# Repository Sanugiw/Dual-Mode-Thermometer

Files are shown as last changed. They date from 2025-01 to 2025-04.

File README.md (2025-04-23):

# 🏥 Dual-Mode Analog Thermometer  

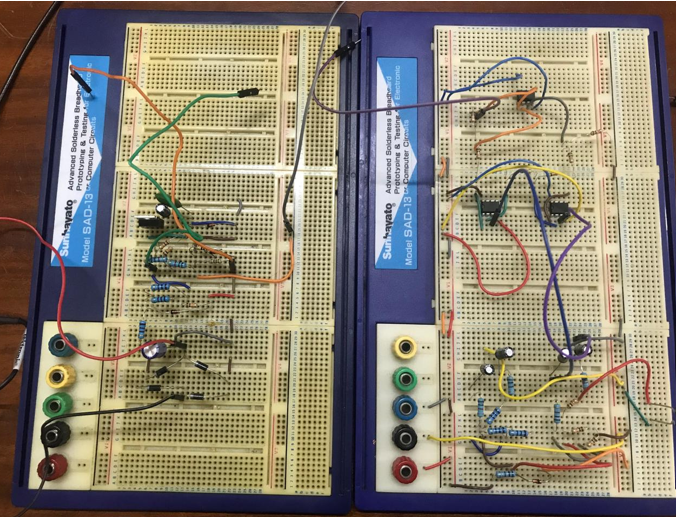
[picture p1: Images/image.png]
Project Banner
 <!-- Add an image of your device or schematic if available -->

## 📌 Overview  
The **Dual-Mode Analog Thermometer** is a precision temperature measurement device designed using **analog components** to ensure high accuracy and reliability. Unlike fully digital thermometers, this design utilizes **thermistors, Wheatstone bridges, and an instrumentation amplifier** for precise temperature readings.  

This project was developed as part of the **EN2091 Laboratory Practice and Projects** module in our 3rd semester, focusing on **hands-on circuit design, sensor integration, and analog signal processing**.  

## ⚡ Features  
✅ **Dual-Mode Functionality** – Toggle switch to switch between **body temperature** and **liquid temperature** modes.  
✅ **High Accuracy** – Uses **thermistors, Wheatstone bridges, and an instrumentation amplifier** for precise readings.  
✅ **OLED Display** – Temperature readings are displayed on an **OLED screen**, with an **Arduino** used solely for display purposes.  
✅ **Stable Power Supply** – Converts **AC to +10V, -10V, and 5V** for reliable operation.  
✅ **Future Expansion** – Plans to integrate a **MUX** for additional modes.  

## 🛠️ Development Tools  
- **Circuit Simulation**: 🖥️ LTspice  
- **Schematic & PCB Design**: 🖊️ Altium Designer  
- **Enclosure Modeling**: 📐 SolidWorks  

## 📷 Hardware Overview  
| Component | Function |
|---|---|
| **Thermistors** (NTC/PTC)  | Temperature sensing  |
| **Wheatstone Bridge**  | Signal conditioning |
| **Instrumentation Amplifier** | Precise signal amplification |
| **OLED Display** | Displays temperature readings |
| **Arduino** | Handles display functionality |
| **Power Supply** | Converts AC to +10V, -10V, and 5V |

## 🧩 Schematic & PCB Design

We designed both the **schematic** and **printed circuit boards (PCBs)** using **Altium Designer**. The project includes:

- 🧠 **Main Thermometer PCB** – Houses the signal conditioning circuit using Wheatstone bridges, thermistors, and an instrumentation amplifier.
- 🔋 **Dual Power Supply PCB** – Converts AC input into stable **+10V, -10V, and 5V** DC outputs. 

### 🖼️ Visuals:
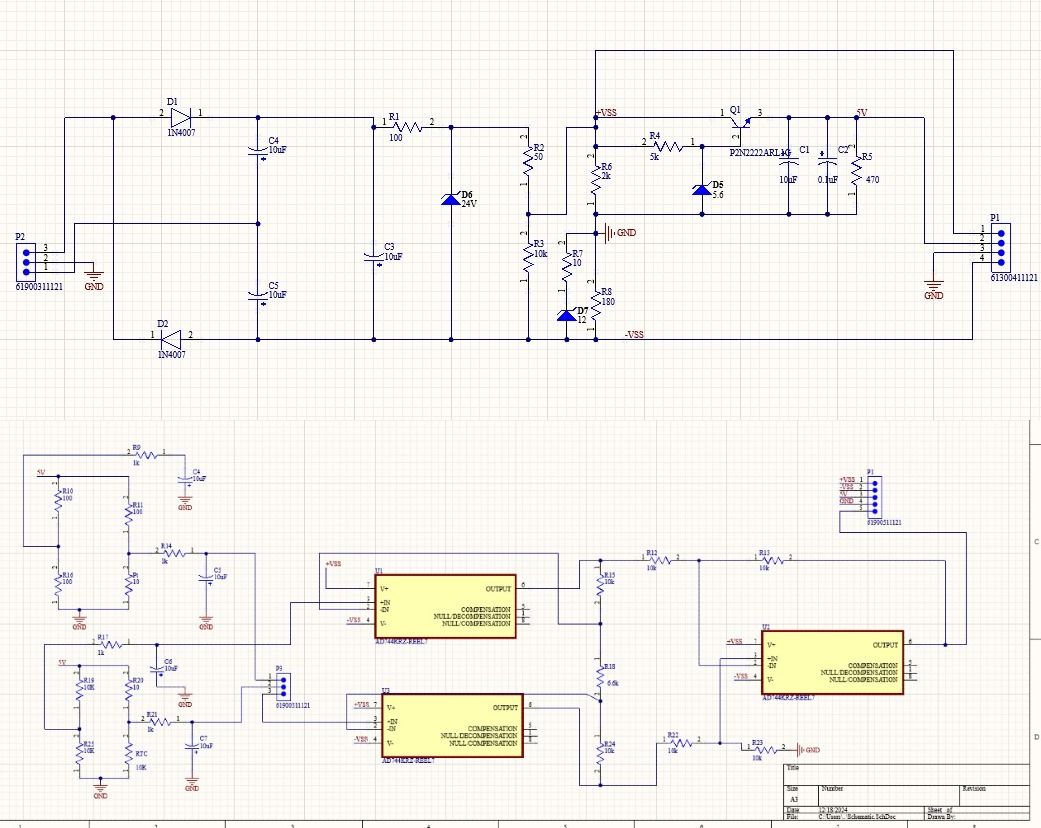
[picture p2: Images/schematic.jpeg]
📐 Schematic

> *Complete circuit schematic designed in Altium Designer.*

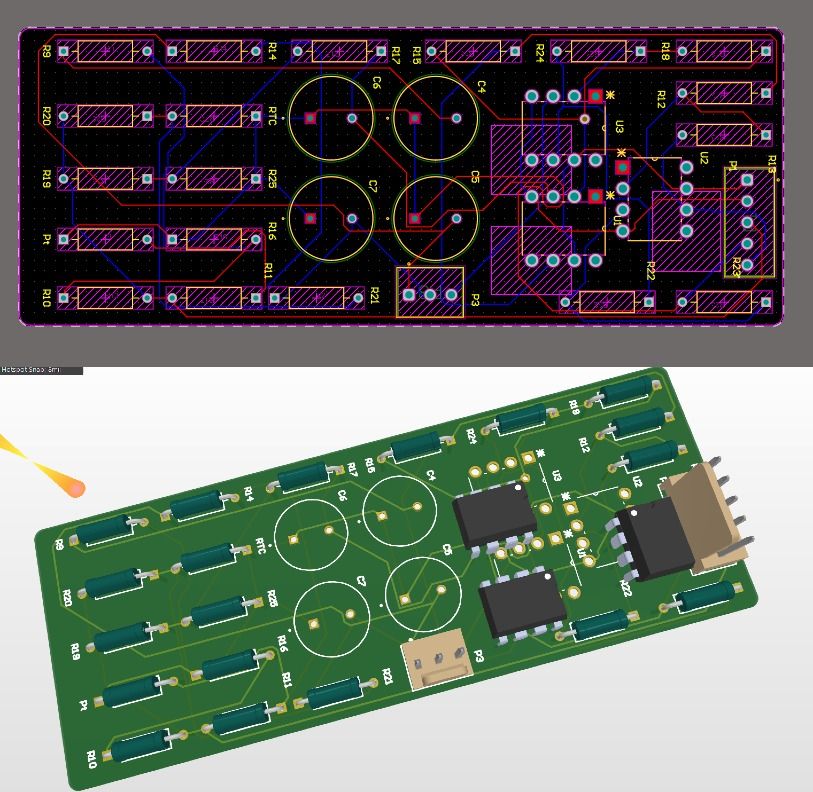
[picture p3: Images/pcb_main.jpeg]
🔧 Sensor PCB

> *Main PCB for the analog thermometer circuit.*

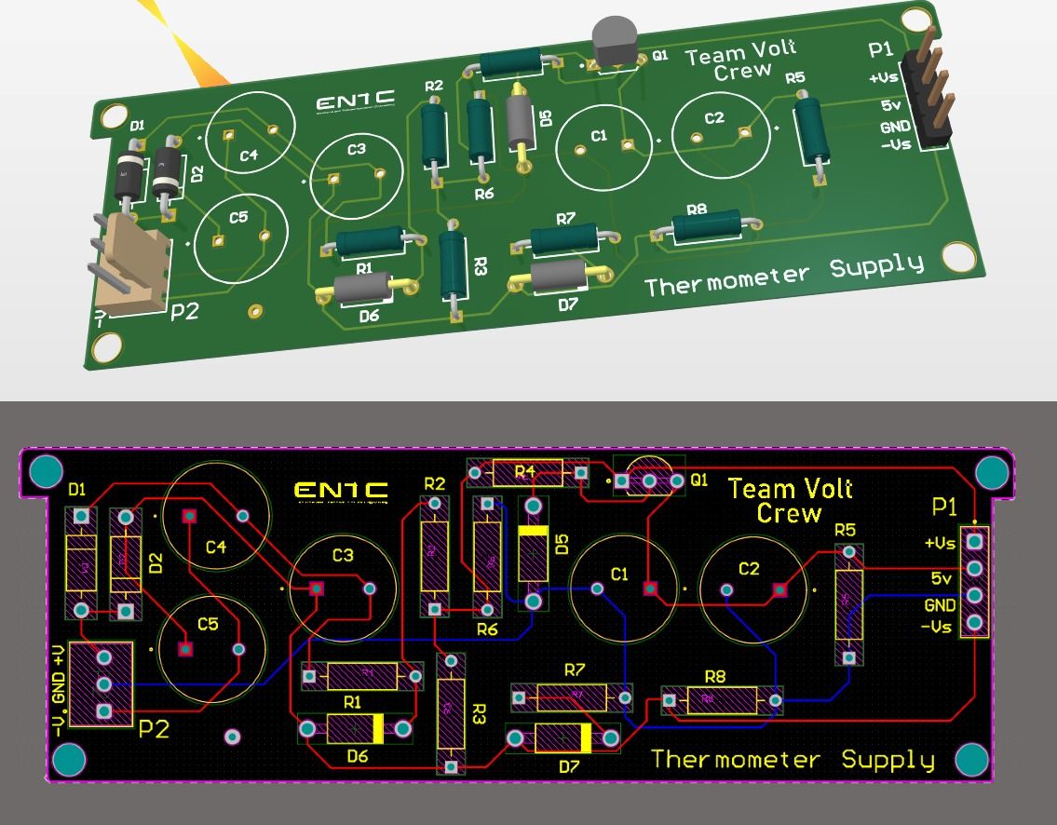
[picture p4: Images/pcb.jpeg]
⚡ Power PCB

> *Power supply PCB providing +10V, -10V, and 5V rails.*

---

## 🧱 Enclosure Design

To protect and house the electronics, we created a **cost-effective 3D-printed enclosure** using **SolidWorks**. The design features:

- 💡 **Compact & Ergonomic** layout for portability and ease of use.
- 🛠️ **Snap-fit joints** for quick assembly without screws.
- 🔄 **Modular access** to switch between body and liquid temperature modes.
- 📏 **Display window** for OLED visibility and button access.

### 🖼️ Visual:
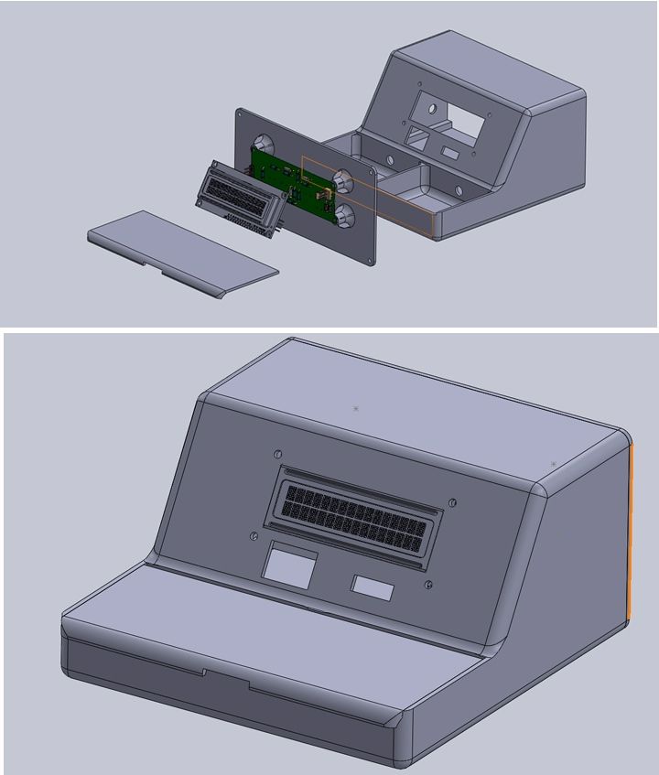
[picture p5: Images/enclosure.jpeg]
🧊 Enclosure

> *3D-modeled enclosure designed for compactness and cost-efficient 3D printing.*

## 🚀 Getting Started  
### 🔧 Requirements  
- **Components**: Thermistors, Wheatstone bridge circuit, instrumentation amplifier, Arduino, OLED display  
- **Software**: LTspice, Altium Designer, SolidWorks, Arduino IDE  

### 🏗️ Setup Instructions  
1. **Assemble the Circuit** using the schematic provided.  
2. **Program the Arduino** with the provided firmware.  
3. **Power the System** using a **+10V, -10V, and 5V power supply**.  
4. **Use the Toggle Switch** to switch between temperature modes.  
5. **Observe the Temperature Readings** on the OLED display.  

## 🤝 Contributors  
- Luchitha Perera
- Benul Wijayarathna
- Sanugi Wickramasinghe
- Hansani Kaumadi

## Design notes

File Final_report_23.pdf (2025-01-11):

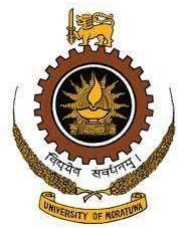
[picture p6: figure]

Department of Electronic & Telecommunication Engineering, University of Moratuwa,
Sri Lanka.

# Dual Thermometer

## Project Report

Group Members

Index No | Name
220472T | Perera P.L.P.
220700T | Wickramasinghe S.D.
220705M | Wijayarathna K.K.B.C.
220735E | Yashodhara M.H.K.

Submitted in partial fulfillment of the requirements for the module EN 2091 Laboratory Practice and Projects

18/12/2024

Dual Thermometer | Team Volt Crew

Abstract

Accurate and simultaneous monitoring of body and fluid temperatures is critical in various clinical and day-to-day applications. This study presents the design and implementation of a dual thermometer system capable of independently measuring body and fluid temperature using separate probes. The system integrates analog electronics and a microcontroller to display temperature data on a digital interface. The body temperature probe employs a high-sensitivity thermistor optimized for rapid and precise response to physiological temperature ranges, while the fluid temperature probe is calibrated for broader thermal conditions. Experimental validation demonstrates a measurement accuracy of ±1°C within the body temperature range (32–42°C) and ±2°C for fluid temperatures (0–100°C). The proposed system offers a cost-effective, reliable, and portable solution for applications requiring concurrent temperature monitoring. Future work will focus on integrating wireless data transmission, improving the accuracy, and enhancing user interface functionality to expand its utility in remote monitoring scenarios.

1

## Contents

1 Introduction | 3
2 Functionality | 3
3 System Architecture | 3
4 Component Selection | 5
5 PCB Design | 6
6 Enclosure Design | 9
7 Software Simulation | 11
8 Hardware Testing | 13
9 Conclusions | 15
10 Future Works | 16
11 Contribution of Group Members | 16

2

## 1 Introduction

Our project focuses on designing and implementing a dual-temperature monitoring system that measures body and fluid temperatures using separate thermistor probes. We developed a custombuilt power supply unit that draws power from the main supply, regulates it, and provides stable operation for the circuit. The temperature readings from the thermistors are processed and displayed on an OLED screen, allowing for clear and real-time monitoring. This versatile system can be used in healthcare, laboratory, and household settings. We achieve a seamless combination of accuracy, reliability, and user-friendly design by integrating analog electronics with digital components.

## 2 Functionality

Our device has 3 main functionalities.

1. Get the input from a thermistor.
2. Amplify the input voltage to a measurable value.
3. Scale the voltage and display the temperature.

## 3 System Architecture

### 3.1 Block Diagram

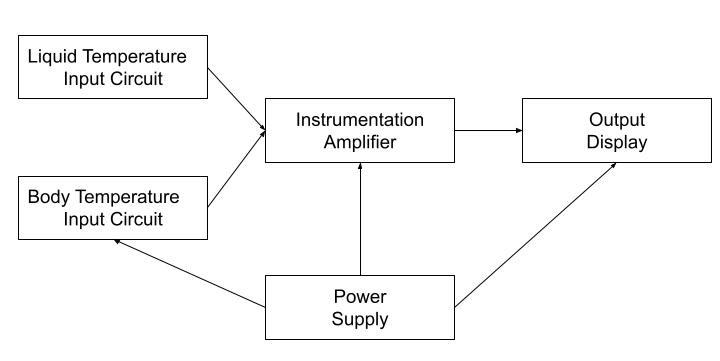
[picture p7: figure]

Figure 1: Block Diagram

The functionality of each block is listed below.

1. Liquid temperature input circuit - Get the temperature input from liquids, which will be converted into a voltage, then linearized through a Winston bridge and filtered through a first order filter.
2. Body temperature input circuit - Get the temperature input from the body, which will be converted into a voltage, then linearized through a Winston bridge and filtered through a first-order filter.

3

3. Instrumentation amplifier - Amplify the input voltage to a sufficient value without distorting it.
4. Output display - Scale the amplified voltage and display the corresponding temperature value in Celsius.
5. Power supply - Supply power to the device. This gives 5V to the 2 input circuits and the display, and 10V to the instrumentation amplifier circuit.

### 3.2 Equations and Theorems

The frequency response of the first-order filters used in the input circuits is given below.

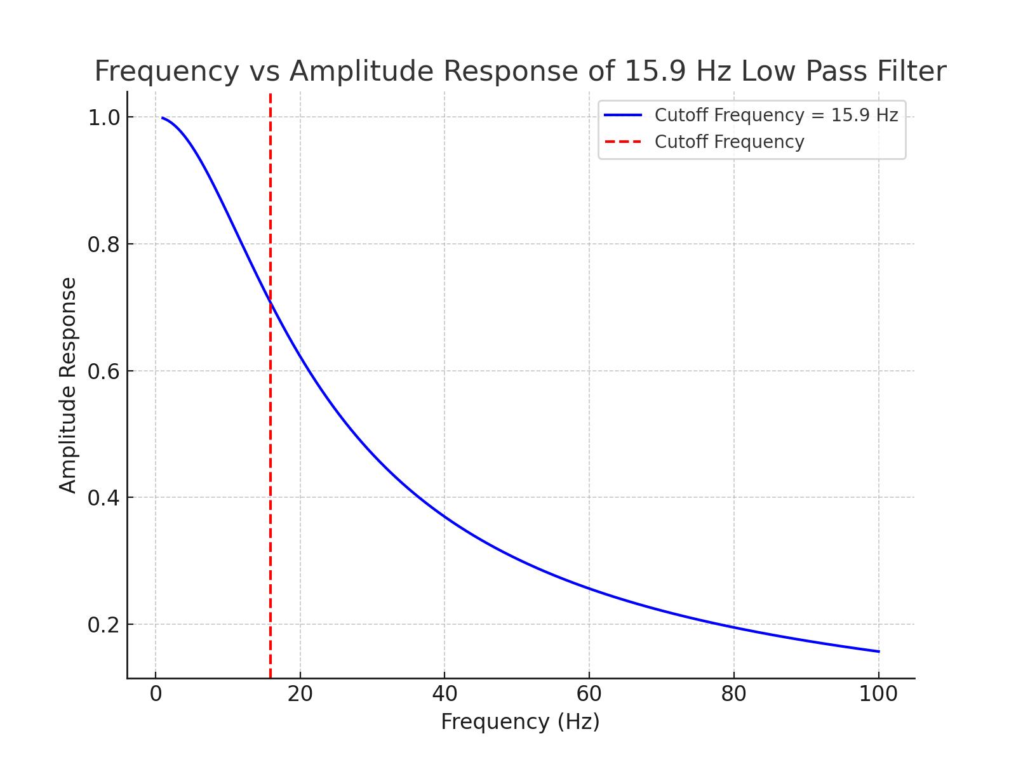
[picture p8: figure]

Figure 2: Frequency Response

The voltage gain of an instrumentation amplifier is given from the below equation.

Av = 1 +

2R
Rf

(1)

The voltage gain of the instrumentation amplifier we used in the circuit is

Av = 1 +

2 ∗ 10
6.6
Av = 4.03

(2)

4

## 4 Component Selection

Component | Reasons for Selection
Transformer (230V to 30V double tap) | • According to the power requirement of the OPAMPs and other circuit components and • proper functionality of the whole circuit
TL702 CP OPAMPs | • Wide supply voltage range (+/-2.25V +/-20V) • Low offset voltage - ensures precise signal amplification • High slew rate (60 V/µs) and stability
TIP41C | • Capability to switch currents up to 500 mA • Maximum voltage rating (Vceo = 60V ) allows it to handle a wide range of supply voltages without breakdown
Instrumentation amplifier | • High accuracy and noise rejection • Simplified Design - easy gain adjustment • High input impedance - prevents loading effects
PT100 thermistor for body temperature measurement | • Provides accurate and stable readings within the typical human body temperature range
NTC 10K thermistor for fluid temperature measurement | • Wide measurement range

Table 1: Components and reasons for their use

5

## 5 PCB Design

After finalizing the circuit, we designed 2 PCBs using Altium Designer.

### 5.1 Power Supply Unit

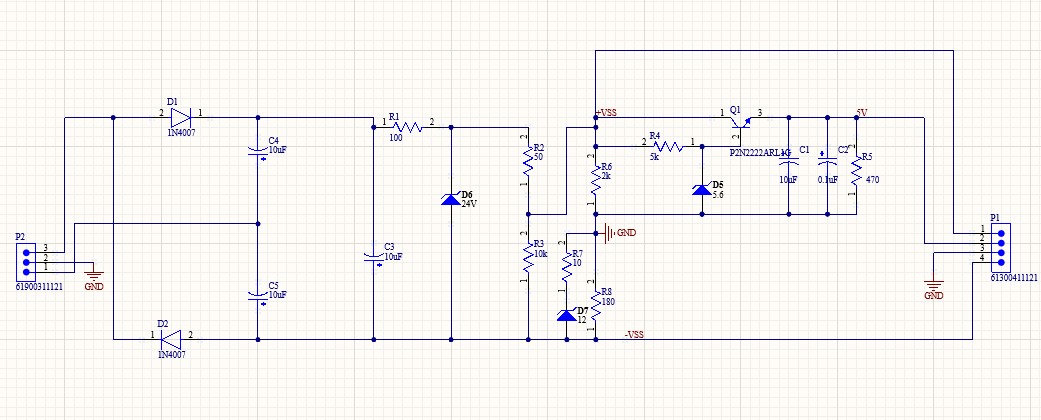
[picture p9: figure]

Figure 3: Power Supply PCB

- A voltage doubler circuit was implemented to generate 30V, which was regulated to 24V using a zener diode.
- For the microcontroller, a 5V supply was made using a BJT regulator.
- The output provides +10V, -10V, 5V and GND, with a center tapped 30V transformer as input.
- The PCB is designed to handle up to 1A current.
- A 2-layer PCB was designed and printed. Assembly was done by team members.

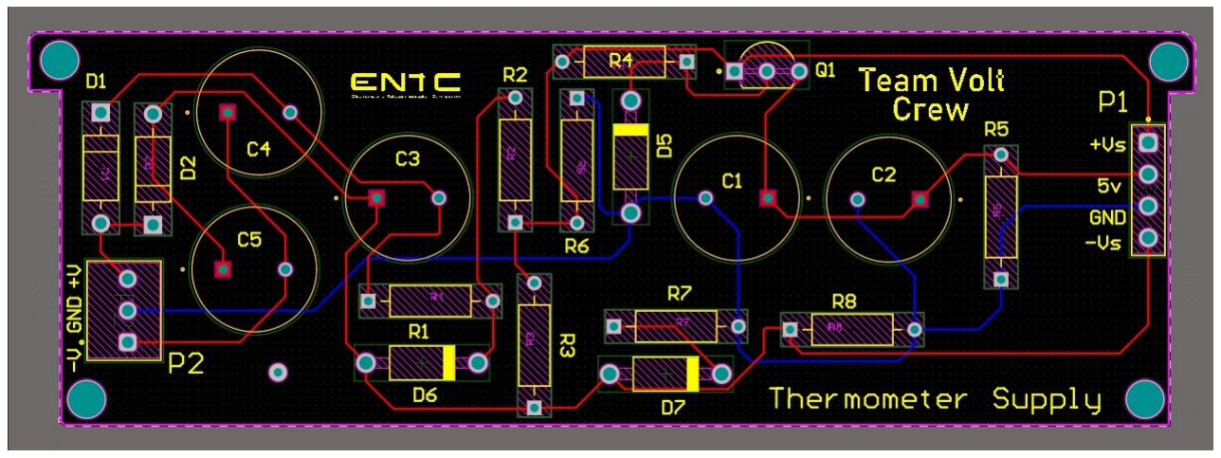
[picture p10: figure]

Figure 4: Power Supply PCB

6

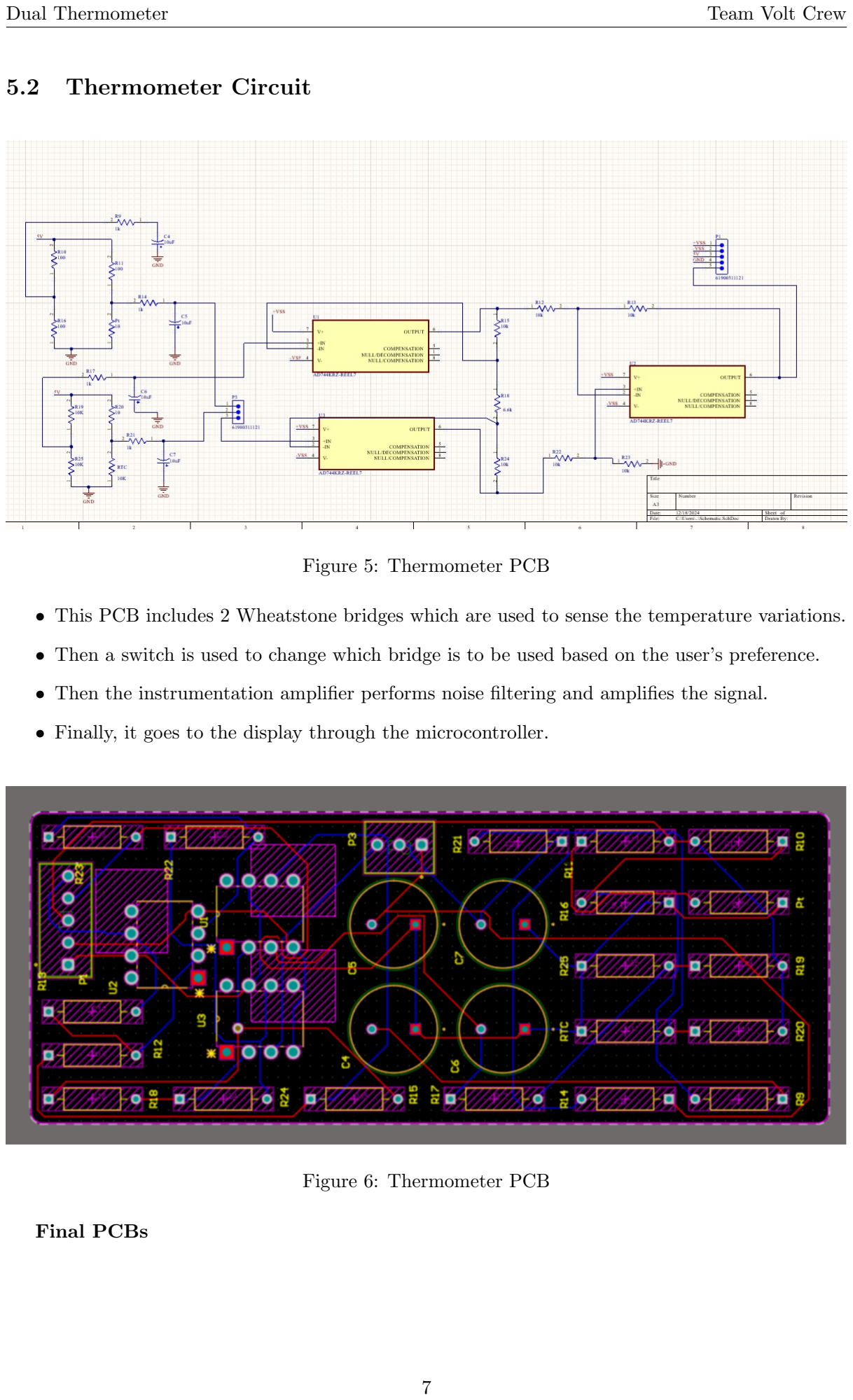
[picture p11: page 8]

### 5.2 Thermometer Circuit

Figure 5: Thermometer PCB

- This PCB includes 2 Wheatstone bridges which are used to sense the temperature variations.
- Then a switch is used to change which bridge is to be used based on the user’s preference.
- Then the instrumentation amplifier performs noise filtering and amplifies the signal.
- Finally, it goes to the display through the microcontroller.

Figure 6: Thermometer PCB

Final PCBs

7

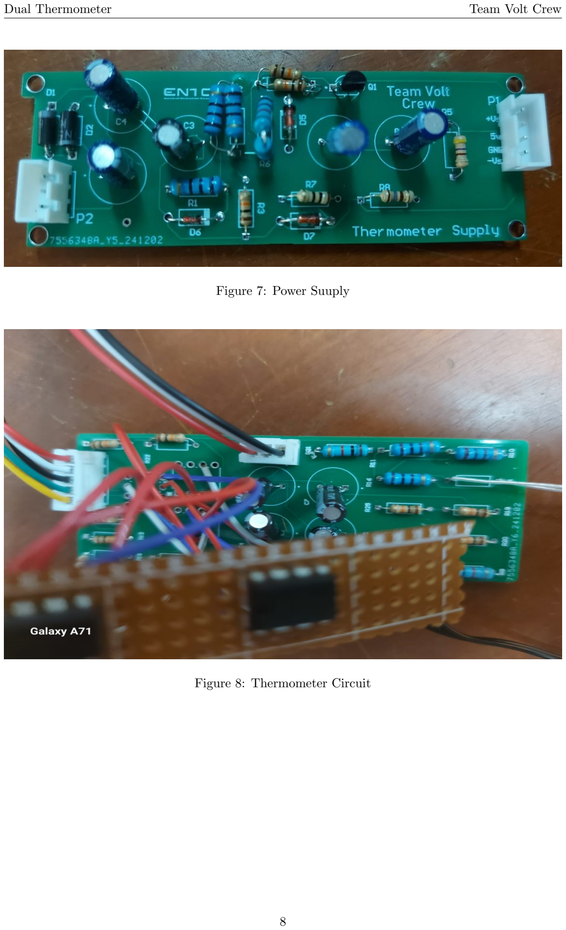
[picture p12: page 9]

Figure 7: Power Suuply

Figure 8: Thermometer Circuit

8

## 6 Enclosure Design

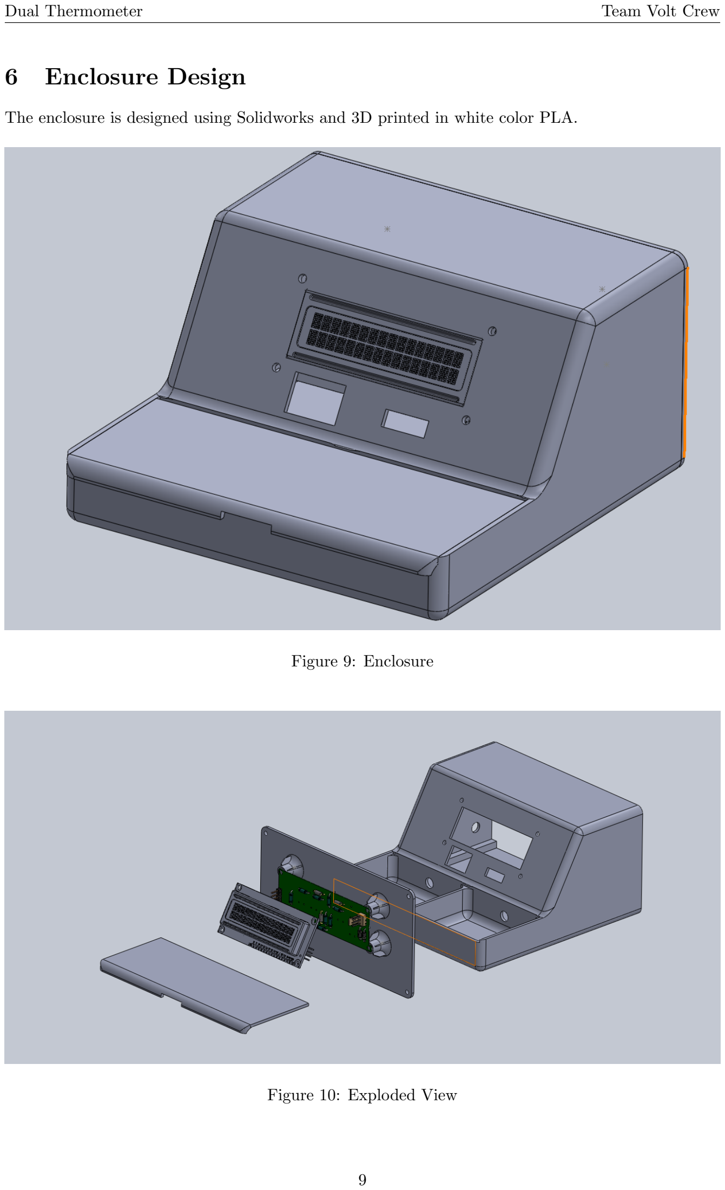
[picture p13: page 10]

The enclosure is designed using Solidworks and 3D printed in white color PLA.

Figure 9: Enclosure

Figure 10: Exploded View

9

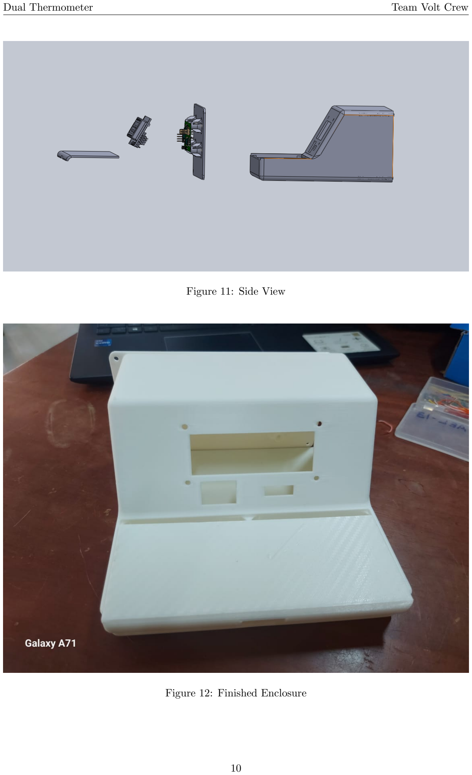
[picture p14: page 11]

Figure 11: Side View

Figure 12: Finished Enclosure

10

## 7 Software Simulation

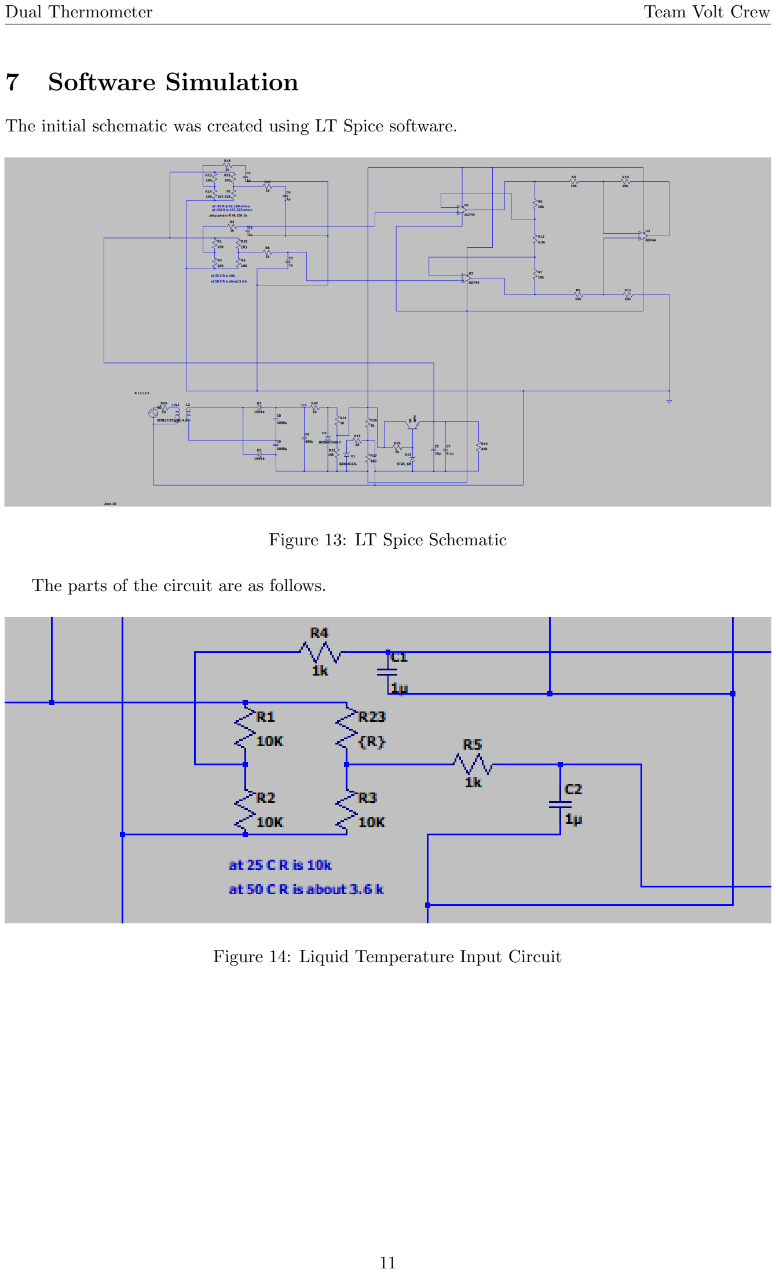
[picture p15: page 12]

The initial schematic was created using LT Spice software.

Figure 13: LT Spice Schematic

The parts of the circuit are as follows.

Figure 14: Liquid Temperature Input Circuit

11

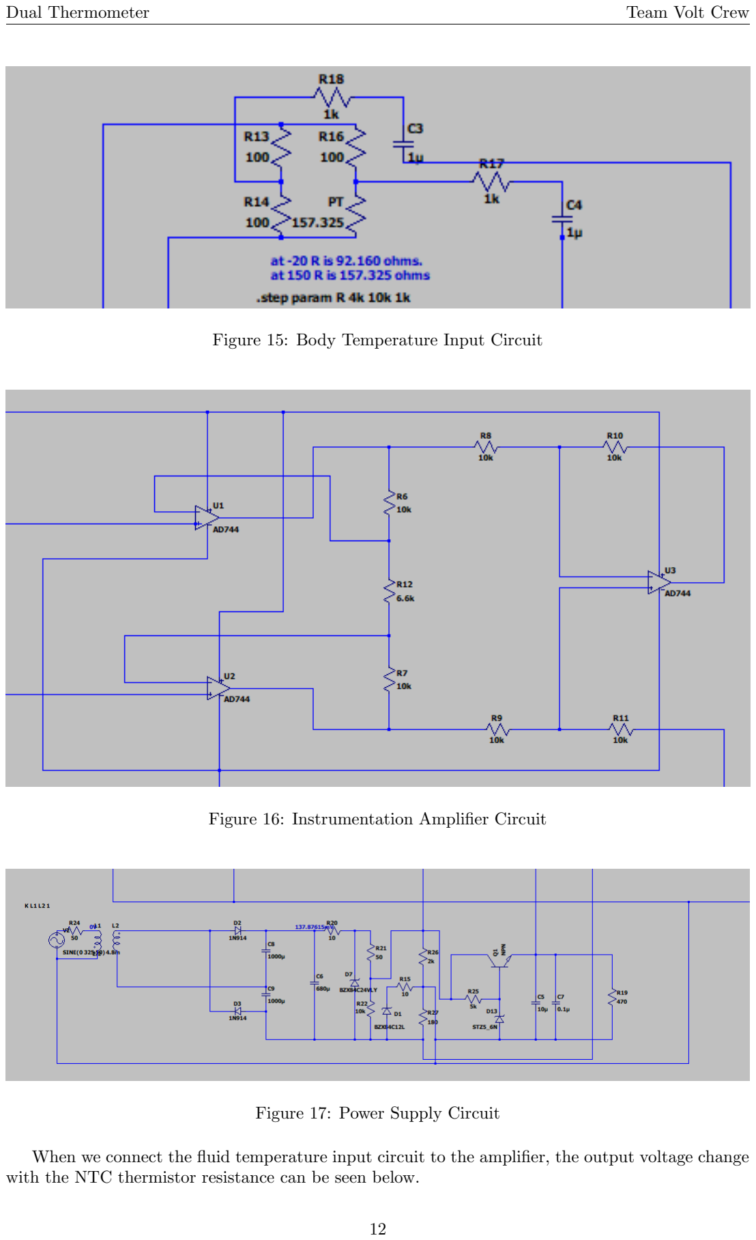
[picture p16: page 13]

Figure 15: Body Temperature Input Circuit

Figure 16: Instrumentation Amplifier Circuit

Figure 17: Power Supply Circuit

When we connect the fluid temperature input circuit to the amplifier, the output voltage change with the NTC thermistor resistance can be seen below.

12

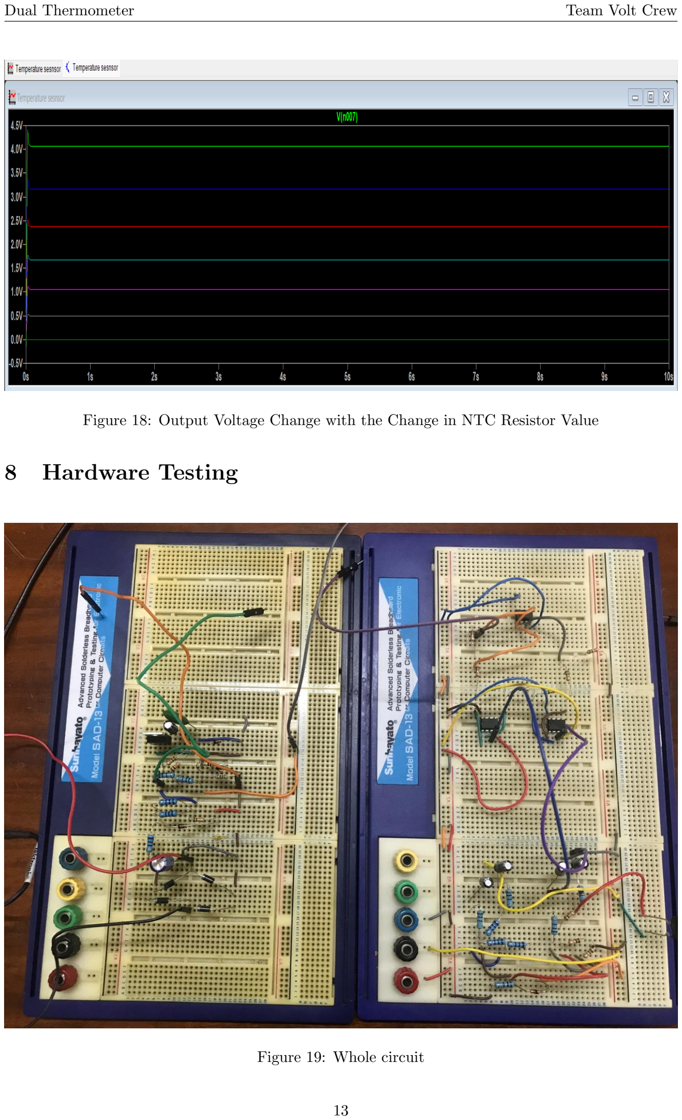
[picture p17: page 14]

Figure 18: Output Voltage Change with the Change in NTC Resistor Value

## 8 Hardware Testing

Figure 19: Whole circuit

13

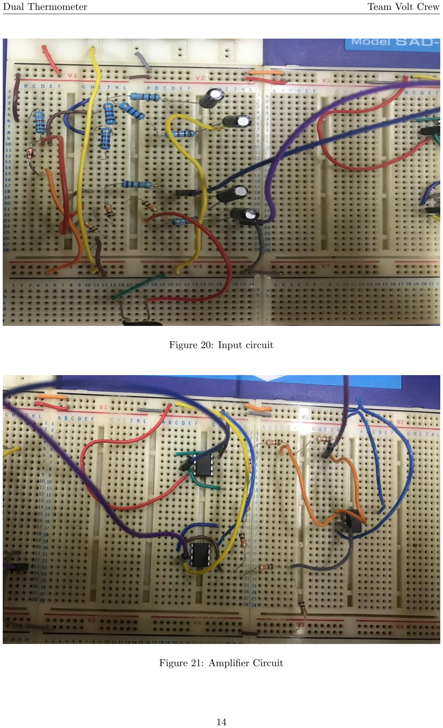
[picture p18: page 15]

Figure 20: Input circuit

Figure 21: Amplifier Circuit

14

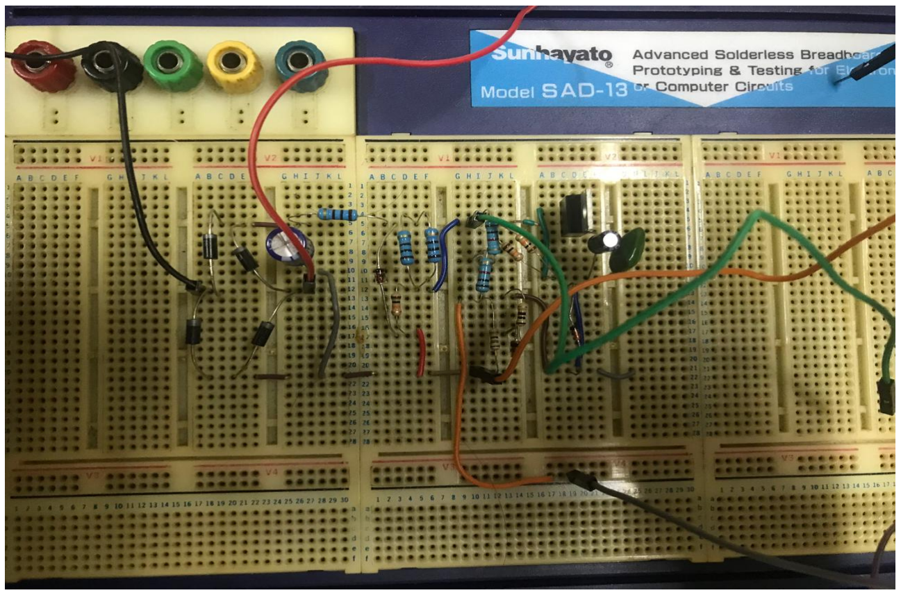
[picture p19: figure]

Figure 22: Power Supply Circuit

We gave a 5V supply to each one of the input circuits and a 10V supply to the op-amps and connected the output to an oscilloscope. Then we could see that the output changes with the temperature of the thermistor i.e its resistance.

## 9 Conclusions

The development of the analog thermometer was a successful endeavor, meeting the project objectives of designing a precise and reliable temperature measurement device. By integrating key circuit components, including Wheatstone bridges, an instrumentation amplifier, and a robust power supply, we achieved consistent and accurate temperature readings across the tested range of 10°C to 50°C.

The calibration process ensured that the thermistor probes (PT100 and NT10K) were optimized for precision, with accuracies of ±0.5°C and ±1.0°C, respectively. The use of a switchable input mechanism and a clear display interface further enhanced the functionality and usability of the device.

This project highlighted the importance of iterative design, calibration, and testing in achieving a reliable final product. The implementation of noise filtering, proper signal conditioning, and careful component selection were critical in ensuring performance stability.

The analog thermometer demonstrates the potential for practical applications in scenarios requiring cost-effective, accurate, and non-digital solutions for temperature measurement. Future improvements, such as incorporating higher-accuracy thermistors and enhanced signal processing techniques, can further refine the device’s performance and broaden its application scope.

15

## 10 Future Works

### 10.1 Improving the Power Supply Circuit

The power supply circuit can be enhanced by incorporating higher-quality components with improved safety ratings, such as components certified for over voltage and over current protection. Considering the direct connection to the main power supply, implementing isolation techniques like optocouplers and fuses will further ensure user safety and circuit reliability.

### 10.2 Enhancing Temperature Scale Accuracy

The signal conditioning circuit can be refined to enhance the accuracy of the temperature scale in our analog project. Using precision operational amplifiers with low noise and offset voltage ensures better amplification of the thermistor signal. Analog filters, such as low-pass filters can be introduced to minimize noise and interference from external sources. Calibration can be improved by incorporating high-precision multi-turn potentiometers for fine-tuning and using stable voltage reference ICs to prevent drift. Additionally, temperature-compensated resistors can be employed in critical parts of the circuit to counteract the effects of ambient temperature changes, resulting in more reliable and accurate temperature readings.

### 10.3 Using Higher-Accuracy Thermistors

Replacing the current thermistors (PT100 and NT10K) with higher-accuracy alternatives, such as digital thermistors or RTDs (Resistance Temperature Detectors) with tighter tolerance, will improve the system’s resolution and reliability. These components can handle wider temperature ranges and offer enhanced linearity, which is critical for high-precision applications.

## 11 Contribution of Group Members

Group Member | Contribution
Perera P.L.P. | Circuit design, Component Selection, PCB design, Soldering
Wickramasinghe S.D. | Circuit design, Enclosure design, Testing and debugging
Wijayarathna K.K.B.C. | Circuit design, Component selection, PCB design, Soldering
Yashoodhara M.H.K. | Circuit design, Enclosure design, Testing and debugging

Table 2: Individual contributions of each group member

16

## References

[1] ”Multi | analog | thermometer | sensor | NTC | 12kOhm | displayed | on | an | LCD,”
Arduino | Forum, | [Online]. | Available: | https://forum.arduino.cc/t/
multi-analog-thermometer-sensor-ntc-12kohm-displayed-on-a-lcd/928655. (https://forum.arduino.cc/t/multi-analog-thermometer-sensor-ntc-12kohm-displayed-on-a-lcd/928655)
[2] Stefano Giangrandi, ”NTC Thermistors,” [Online]. Available: https://www.giangrandi.org/electronics/ntc/ntc.shtml. (https://www.giangrandi.org/electronics/ntc/ntc.shtml)
[3] ”Temperature | Measurement | Using | NTC | Thermistors,” | Jameco | Electron-
ics, | [Online]. | Available: | https://www.jameco.com/Jameco/workshop/TechTip/
temperature-measurement-ntc-thermistors.html. (https://www.jameco.com/Jameco/workshop/TechTip/temperature-measurement-ntc-thermistors.html)
[4] ”NTC Thermistor Interfacing with PIC18F4550,” ElectronicWings, [Online]. Available: https: //www.electronicwings.com/pic/ntc-thermistor-interfacing-with-pic18f4550.
[5] G. Yadav and B. Singh, ”Design of Temperature Measuring Instrument Using NTC
Thermistor of Fe2TiO5 | Based on Microcontroller ATmega 328,” ResearchGate, [On-
line]. Available: | https://www.researchgate.net/publication/337444121_Design_of_
temperature_measuring_instrument_using_NTC_thermistor_of_Fe_2_TiO_5_based_on_ microcontroller_ATmega_328. (https://www.researchgate.net/publication/337444121_Design_of_temperature_measuring_instrument_using_NTC_thermistor_of_Fe_2_TiO_5_based_on_microcontroller_ATme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)

17

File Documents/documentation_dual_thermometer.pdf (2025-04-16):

University of Moratuwa

Faculty of Engineering

Department of Electronic & Telecommunication Engineering


EN2091 : Laboratory Practice and Projects

Team Volt Crew

Project Report

Group Members

Index No | Name
220472T | Perera P.L.P.
220700T | Wickramasinghe S.D.
220705M | Wijayarathna K.K.B.C.
220735E | Yashodhara M.H.K.

1

# Contents

2

## 1 Introduction

Our project focuses on designing and implementing a dual-temperature monitoring system capable of measuring both body and fluid temperatures using separate thermistor probes. We developed a custom-built power supply unit that draws power from the main supply, regulates it, and provides stable operation for the circuit. The temperature readings from the thermistors are processed and displayed on an OLED screen, allowing for clear and real-time monitoring. This system is versatile and can be used in healthcare, laboratory, and household settings. By integrating analog electronics with digital components, we achieve a seamless combination of accuracy, reliability, and user-friendly design.

## 2 Functionality

Our device has 3 main functionalities.

1. Get the input from a thermistor.
2. Amplify the input voltage to a measurable value.
3. Scale the voltage and display the temperature.

## 3 System Model

### 3.1 Block Diagram


Figure 1: Block Diagram

The functionality of each block is listed below.

3

1. Liquid temperature input circuit - Get the temperature input from liquids, which will be converted into a voltage, then linearized through a Winston bridge and filtered through a first-order filter.
2. Body temperature input circuit - Get the temperature input from the body, which will be converted into a voltage, then linearized through a Winston bridge and filtered through a first-order filter.
3. Instrumentation amplifier - Amplify the input voltage to a sufficient value without distorting it.
4. Output display - Scale the amplified voltage and display the corresponding temperature value in Celsius.
5. Power supply - Supply power to the device. This gives 5V to the 2 input circuits and the display, and 10V to the instrumentation amplifier circuit.

### 3.2 Design Parameters

Thermistor Selection and Application

To accommodate varying temperature measurement requirements, two thermistor types were utilized.

- NTC10K Thermistor: Chosen for its ability to measure a wide temperature range, this thermistor was used for environmental temperature readings. Its high sensitivity across a broad spectrum made it suitable for general-purpose monitoring.
- PT100 Thermistor: Specifically selected for body temperature measurements, this thermistor provided high precision and stability within the critical range of 10°C to 50°C. This narrower range aligned with human body temperature requirements, ensuring accurate and reliable readings.

Temperature Range

The thermometer was designed to measure temperatures spanning.

- Environmental Temperature: From -20°C to 100°C using the NTC10K thermistor.
- Body Temperature: From 10°C to 50°C using the PT100 thermistor.

Power Supply

The device operates on a dual supply system providing +10V, -10V, and 5V outputs.

- A voltage doubler circuit generating 30V, regulated to 24V using a zener diode.

4

- A 5V supply for the microcontroller implemented via a BJT regulator.

The circuit is capable of handling currents up to 1A, ensuring stable and reliable operation.

Signal Conditioning

To accurately process the resistance variations from the thermistors, the design incorporated

- Two Wheatstone bridge circuits for resistance-to-voltage conversion.
- An instrumentation amplifier for noise filtering and precise signal amplification.

Switching Mechanism

A manual switch was integrated to allow users to select between the two thermistors based on the desired measurement. This ensured flexibility in functionality while maintaining simplicity in operation.

Display and Interface

Temperature readings were displayed using an analog output interface, prioritizing clear visibility and ease of interpretation.

Physical Dimensions and Enclosure

The enclosure was compactly designed using SolidWorks and 3D-printed with white PLA material. The design emphasized ergonomic handling, durability, and portability.

Safety and Reliability

The power supply circuit included over-voltage and over-current protection mechanisms, ensuring user safety and device longevity. Additionally, robust components were used to enhance overall reliability.

5

6

### 3.3 Component Selection

Component | Reasons for Selection
Transformer (230V to 30V double tap) | • According to the power requirement of the OPAMPs and other circuit components • Proper functionality of the whole circuit
TL702 CP OPAMPs | • Wide supply voltage range • Low Offset voltage - ensures precise signal amplification • High slew rate (60 V/µs) and stability
TIP41C | • Capability to switch currents up to 500 mA • Maximum voltage rating (Vceo = 60V ) allows it to handle a wide range of supply voltages without breakdown
Instrumentation amplifier | • High accuracy and noise rejection • Simplified design - easy gain adjustment • High input impedance - prevents loading effects
PT100 thermistor for body temperature measurement | • Provides accurate and stable readings within the typical human body temperature range
NTC 10K thermistor for fluid temperature measurement | • Wide measurement range

Table 1: Components and reasons for their use 7

## 4 Schematic

The initial schematic was created using LT Spice software.

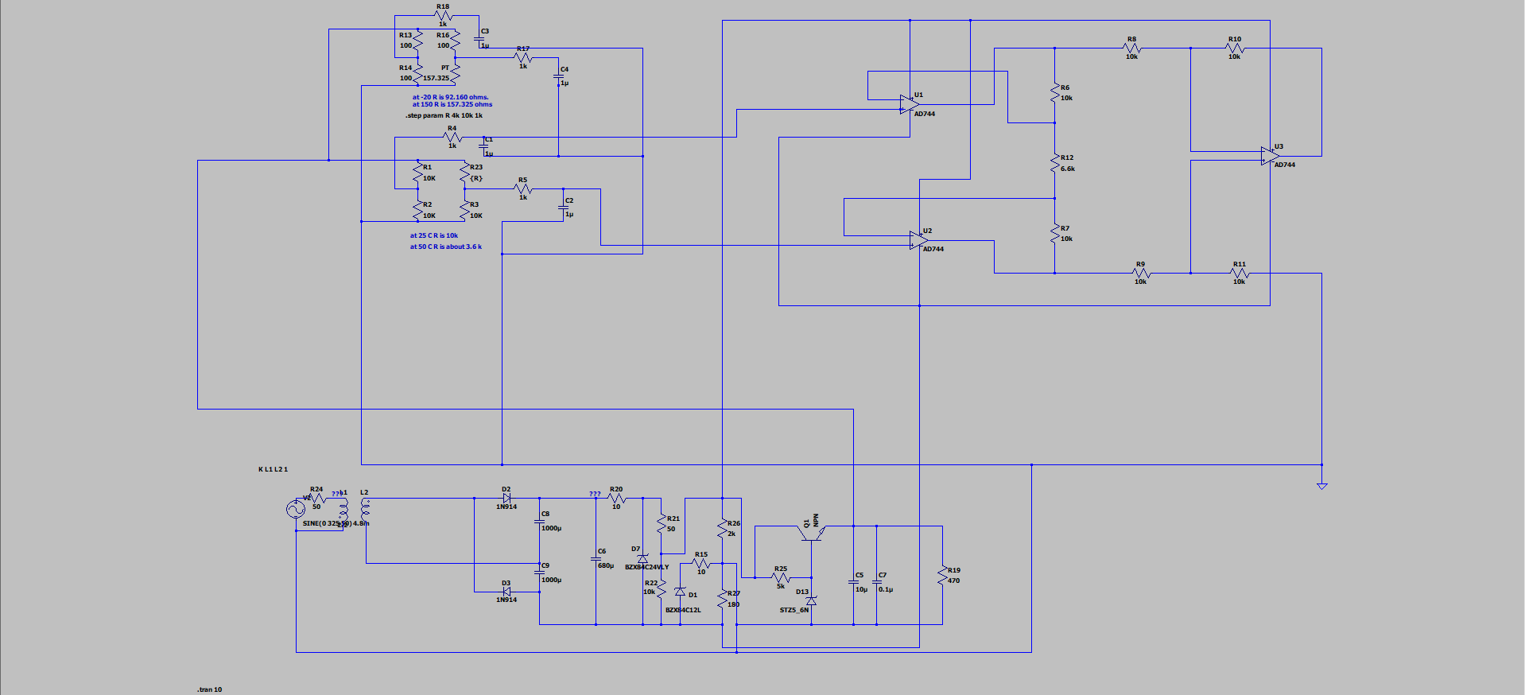
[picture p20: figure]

Figure 2: LT Spice Schematic

The parts of the circuit are as follows.

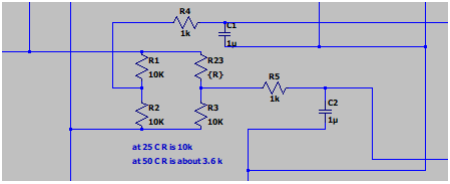
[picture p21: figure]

Figure 3: Liquid Temperature Input Circuit

8

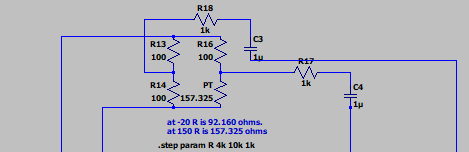
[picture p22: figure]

Figure 4: Body Temperature Input Circuit

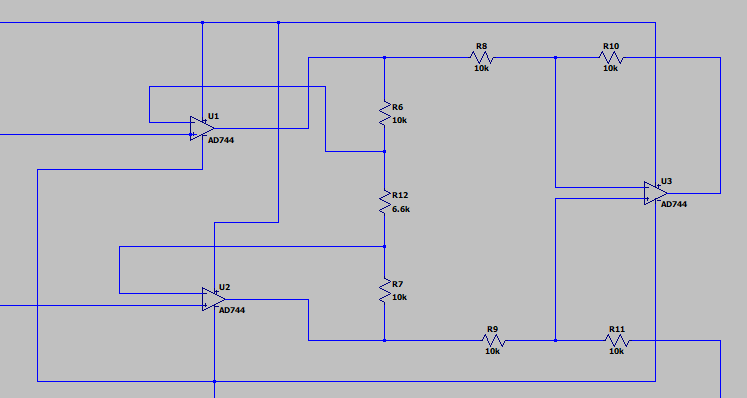
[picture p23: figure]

Figure 5: Instrumentation Amplifier Circuit

9

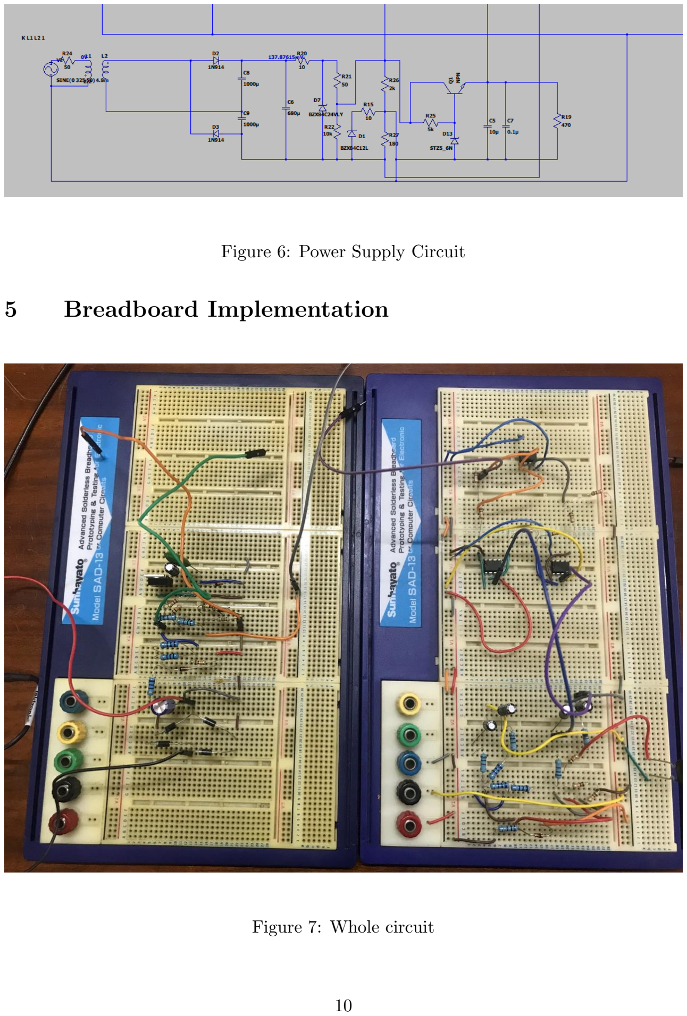
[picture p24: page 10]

Figure 6: Power Supply Circuit

## 5 Breadboard Implementation

Figure 7: Whole circuit

10

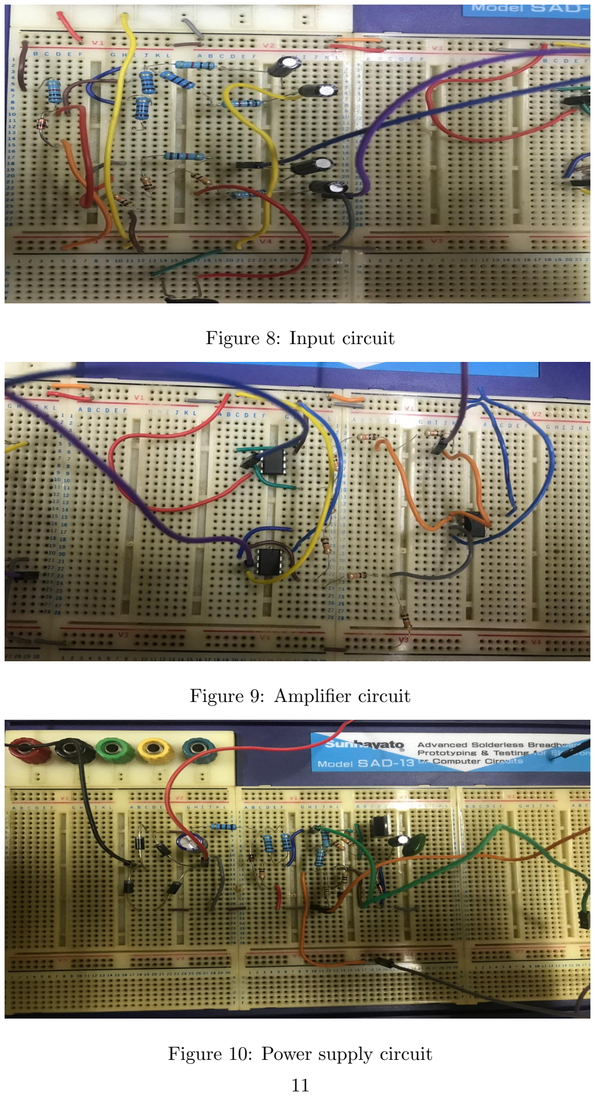
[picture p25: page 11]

Figure 8: Input circuit

Figure 9: Amplifier circuit

Figure 10: Power supply circuit

11

## 6 PCB Design

After finalizing the circuit, we designed 2 PCBs using Altium Designer.

### 6.1 Power Supply Unit

- A voltage doubler circuit was implemented to generate 30V, which was regulated to 24V using a zener diode.
- For the microcontroller, a 5V supply was made using a BJT regulator.
- The output provides +10V, -10V, 5V and GND, with a center tapped 30V transformer as input.
- The PCB is designed to handle up to 1A current.
- A 2-layer PCB was designed and printed. Assembly was done by team members.

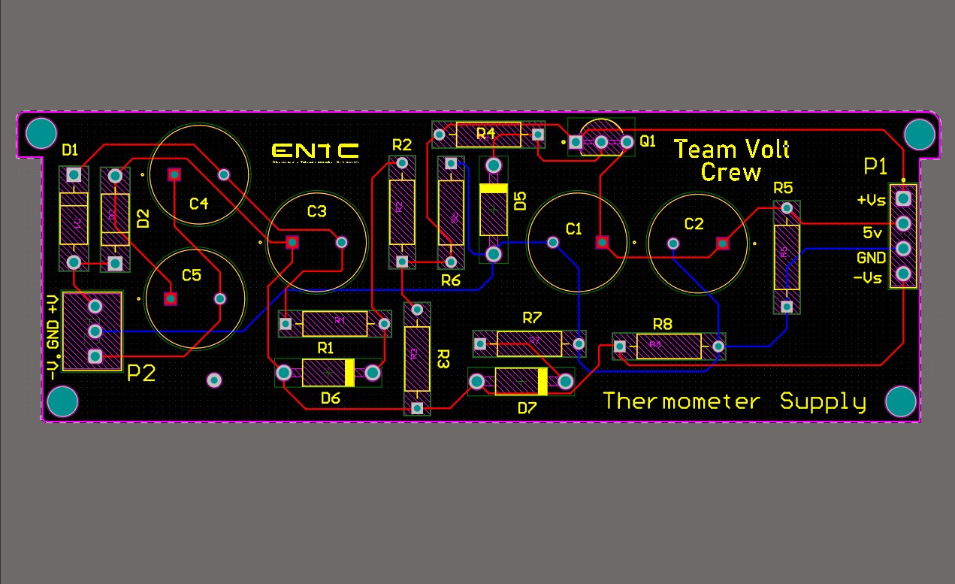
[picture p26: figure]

Figure 11: Power Supply PCB

### 6.2 Thermometer Circuit

- This PCB includes 2 Wheatstone bridges which are used to sense the temperature variations.
- Then a switch is used to change which bridge is to be used based on the user’s preference.
- Then the instrumentation amplifier performs noise filtering and amplifies the signal.
- Finally, it goes to the display through the microcontroller.

12

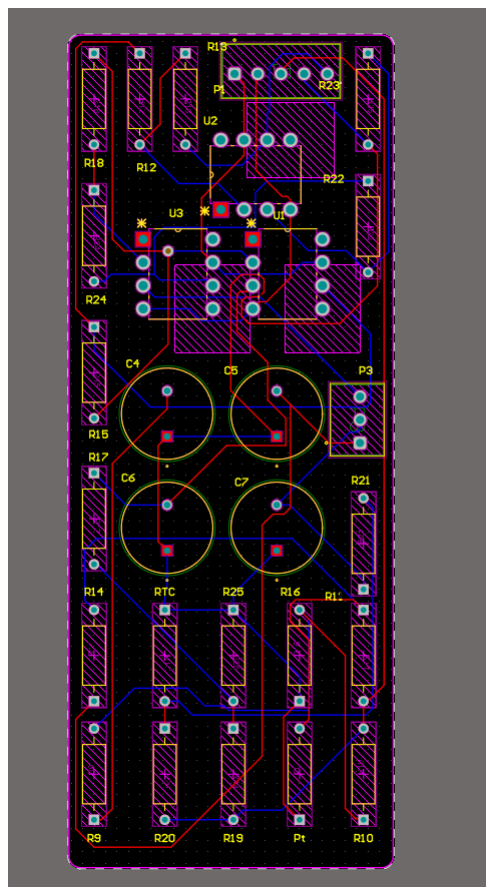
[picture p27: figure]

Figure 12: Thermometer PCB

Final PCBs

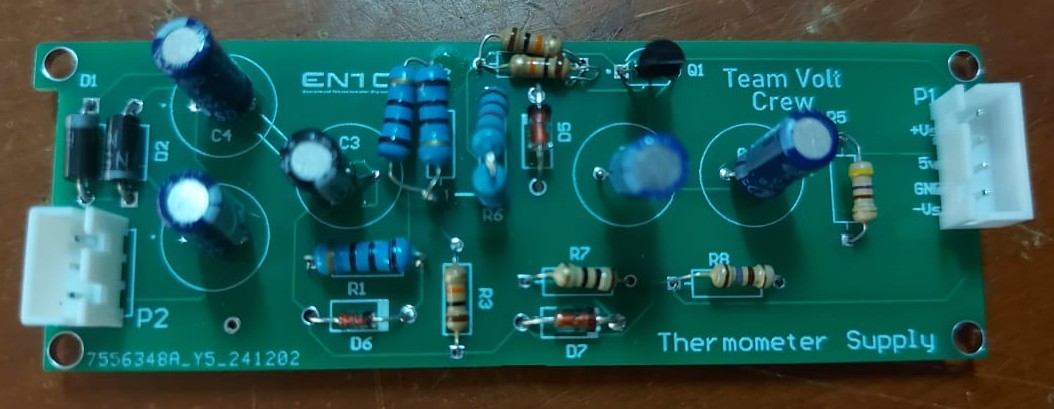
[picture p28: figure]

Figure 13: Power Suuply

13

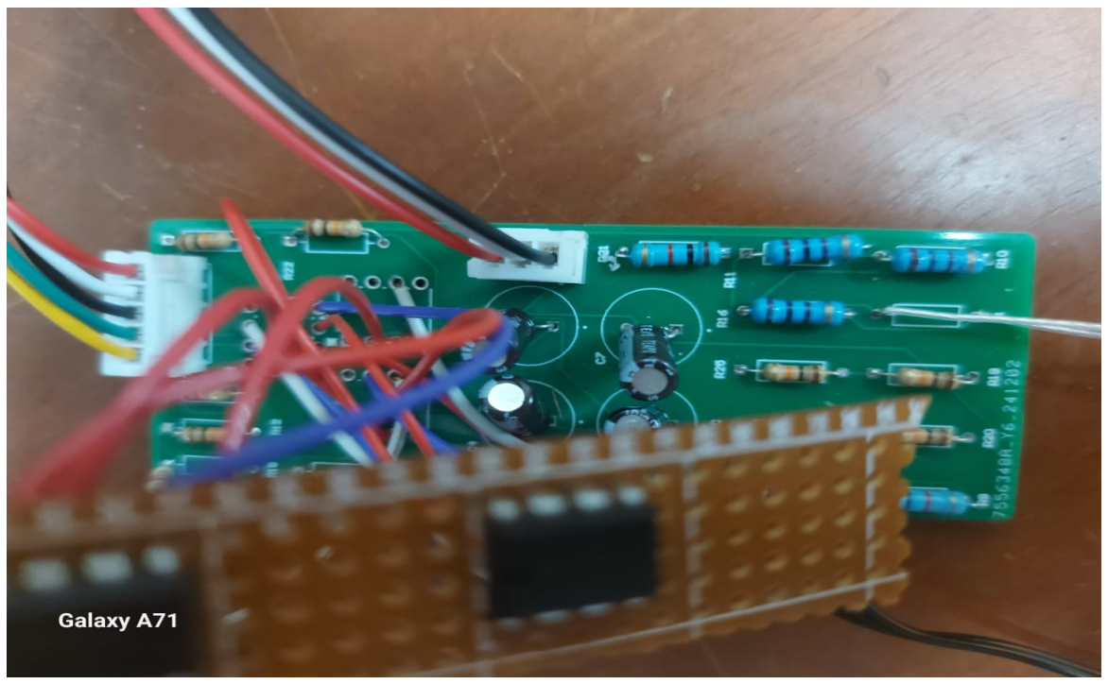
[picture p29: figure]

Figure 14: Thermometer Circuit

## 7 Enclosure Design

The enclosure is designed using Solidworks and 3D printed in white color PLA.

14


Figure 15: Enclosure

Figure 16: Exploded View

15


Figure 17: Side View

Figure 18: Finished Enclosure

16

## 8 Individual Contributions

Group Member | Contribution
Perera P.L.P. | Circuit design, Component Selection, PCB design, Soldering
Wickramasinghe S.D. | Circuit design, Enclosure design, Testing and debugging
Wijayarathna K.K.B.C. | Circuit design, Component selection, PCB design, Soldering
Yashoodhara M.H.K. | Circuit design, Enclosure design, Testing and debugging

Table 2: Individual contributions of each group member

## 9 Simulation Results

We simulated the circuit using LT Spice.
When we connect the fluid temperature input circuit to the amplifier, the output voltage change with the NTC thermistor resistance can be seen below.


Figure 19: Output Voltage Change with the Change in NTC Resistor Value

17

## 10 Test Results

We conducted a series of tests to evaluate the accuracy and performance of the analog thermometer across a range of temperatures.

### 10.1 Temperature Range and Calibration

The thermometer was tested with temperatures between 10°C and 50°C using calibrated reference thermometers for validation. Each thermistor probe (PT100 and NT10K) was individually calibrated by measuring output voltages at known temperature points. These measurements were used to establish a precise temperature scale for each probe.

### 10.2 Accuracy

After calibration, the thermometer achieved:

- PT100 Probe: Accuracy within ±1.0°C.
- NT10K Probe: Accuracy within ±2.0°C.

### 10.3 Stability and Reliability

The device demonstrated consistent performance during repeated tests under identical conditions. The noise-filtering capabilities of the instrumentation amplifier and the Wheatstone bridge design contributed to stable and reliable readings.

### 10.4 User Interface Validation

The switching mechanism for selecting thermistor probes functioned seamlessly, and the LCD display provided clear and accurate readings throughout the testing process. These results confirm the thermometer’s ability to deliver precise and repeatable temperature measurements, fulfilling the project’s objectives effectively.

## 11 Conclusions

The development of the analog thermometer was a successful endeavor, meeting the project objectives of designing a precise and reliable temperature measurement device. By integrating key circuit components, including Wheatstone bridges, an instrumentation amplifier, and a robust power supply, we achieved consistent and accurate temperature readings across the tested range of 10°C to 50°C.

The calibration process ensured that the thermistor probes (PT100 and NT10K) were optimized for precision, with accuracies of ±0.5°C and ±1.0°C, respectively. The use of a switchable input mechanism and a clear display interface further enhanced the functionality and usability of the device.

18

This project highlighted the importance of iterative design, calibration, and testing in achieving a reliable final product. The implementation of noise filtering, proper signal conditioning, and careful component selection were critical in ensuring performance stability.

The analog thermometer demonstrates the potential for practical applications in scenarios requiring cost-effective, accurate, and non-digital solutions for temperature measurement. Future improvements, such as incorporating higher-accuracy thermistors and enhanced signal processing techniques, can further refine the device’s performance and broaden its application scope.

## 12 Future Works

### 12.1 Improving the Power Supply Circuit

The power supply circuit can be enhanced by incorporating higher-quality components with improved safety ratings, such as components certified for over voltage and over current protection. Considering the direct connection to the main power supply, implementing isolation techniques like optocouplers and fuses will further ensure user safety and circuit reliability.

### 12.2 Enhancing Temperature Scale Accuracy

The signal conditioning circuit can be refined to enhance the accuracy of the temperature scale in our analog project. Using precision operational amplifiers with low noise and offset voltage ensures better amplification of the thermistor signal. Analog filters, such as low-pass filters can be introduced to minimize noise and interference from external sources. Calibration can be improved by incorporating high-precision multi-turn potentiometers for fine-tuning and using stable voltage reference ICs to prevent drift. Additionally, temperature-compensated resistors can be employed in critical parts of the circuit to counteract the effects of ambient temperature changes, resulting in more reliable and accurate temperature readings.

### 12.3 Using Higher-Accuracy Thermistors

Replacing the current thermistors (PT100 and NT10K) with higher-accuracy alternatives, such as digital thermistors or RTDs (Resistance Temperature Detectors) with tighter tolerance, will improve the system’s resolution and reliability. These components can handle wider temperature ranges and offer enhanced linearity, which is critical for applications requiring high precision.

19

## 13 References

”Multi analog thermometer sensor NTC 12kOhm displayed on an LCD,” Arduino Forum, [Online].

Stefano Giangrandi, ”NTC Thermistors,” [Online].

”Temperature Measurement Using NTC Thermistors,” Jameco Electronics, [Online].

”NTC Thermistor Interfacing with PIC18F4550,” ElectronicWings, [Online].

G. Yadav and B. Singh, ”Design of Temperature Measuring Instrument Using NTC Thermistor of Fe2TiO5 Based on Microcontroller ATmega 328,” ResearchGate, [Online].

20

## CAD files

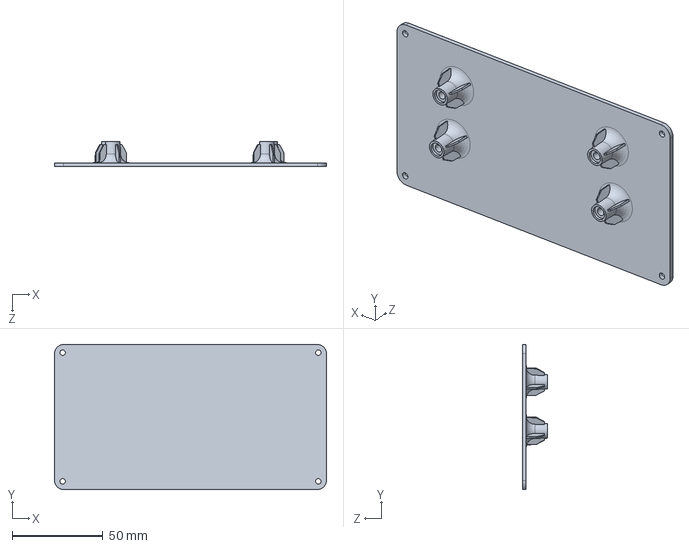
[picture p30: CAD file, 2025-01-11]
Enclosure/Part2.SLDPRT
150.0 x 80.0 x 13.7 mm

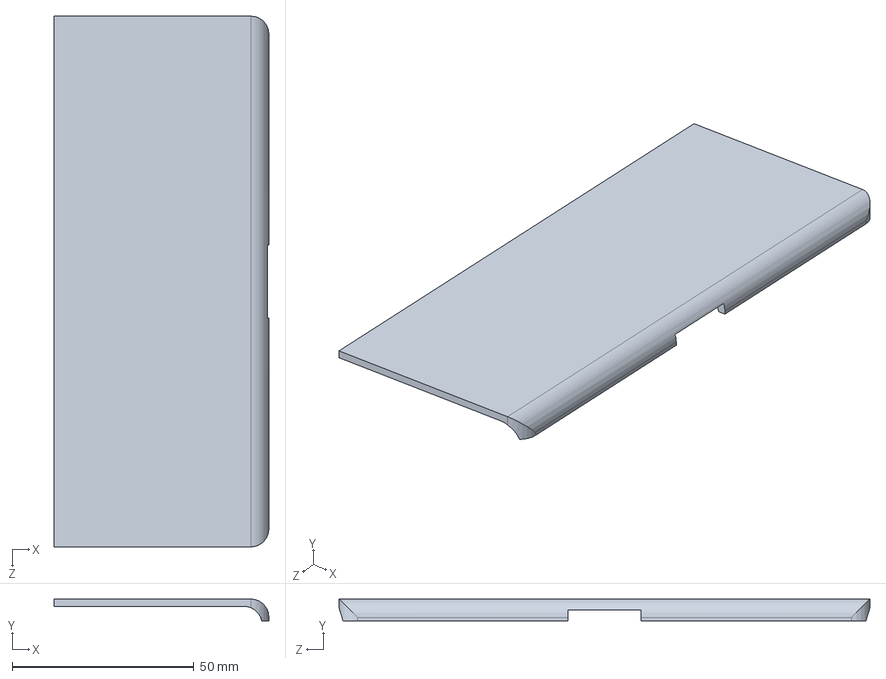
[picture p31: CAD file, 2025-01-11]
Enclosure/Lid.SLDPRT
59.1 x 6.00 x 146.0 mm

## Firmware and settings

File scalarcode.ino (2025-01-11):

#define PIN_D15 15 // Voltage V1 connected to GPIO 15
#define PIN_D2 2   // Voltage V2 connected to GPIO 2

void setup() {
  Serial.begin(9600); // Initialize serial communication
  analogReadResolution(12); // Set ADC resolution (12-bit for ESP32)
}

void loop() {
  // Read raw ADC value from PIN_D15
  int rawV1 = analogRead(PIN_D15); // analogRead returns an integer value (0–4095 for 12-bit resolution)

  Serial.print("Raw value: ");
  Serial.println(rawV1);

  float temp = 0; // Initialize temp to avoid errors when the condition isn't met
    // Calculate temp using proper floating-point division
  temp = rawV1 * (15.0 / 200.0) - 62; 

  Serial.print("Temp = ");
  Serial.println(temp); // Print temp, which will remain 0 if the condition is not met

  delay(2000); // Delay for 5 seconds
}
